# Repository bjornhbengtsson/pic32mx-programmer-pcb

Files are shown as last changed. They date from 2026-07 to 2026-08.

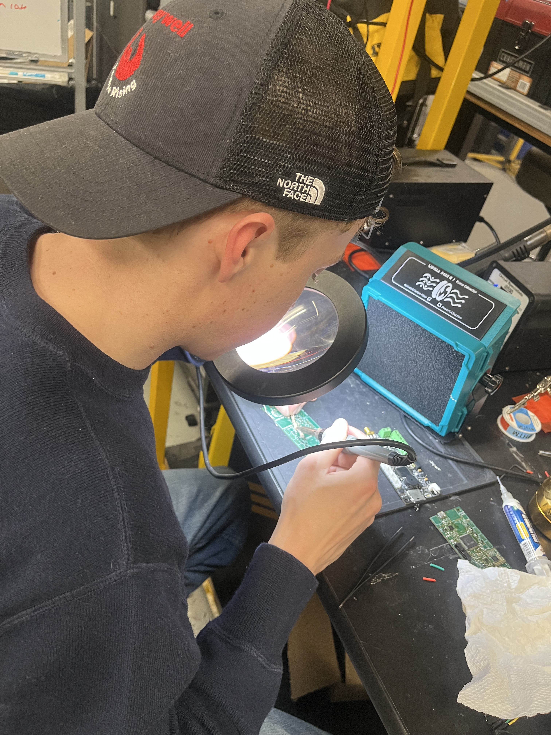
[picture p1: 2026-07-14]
images/Soldering.jpeg

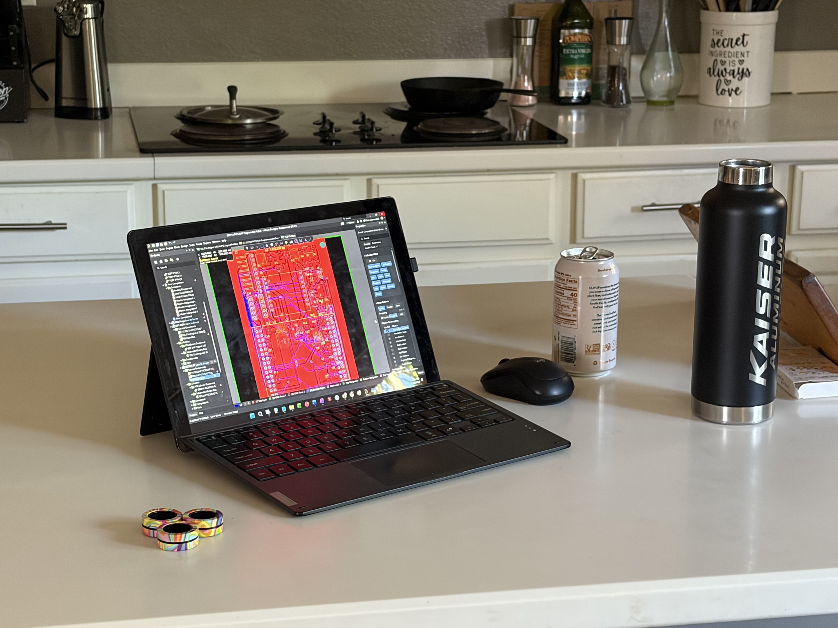
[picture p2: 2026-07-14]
images/Designing.jpeg

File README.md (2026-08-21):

# PIC32MX 64-Pin Programmer PCB

A reusable socketed programmer, USB bootloader, firmware flashing, and hardware-validation platform for 64-pin PIC32MX microcontrollers.

Programmer_Board_Product

[Programmer_PCB_REACH.pdf](https://github.com/user-attachments/files/31288978/Programmer_PCB_REACH.pdf)


## Overview

This project provides a development and test platform for PIC32MX 64-pin MCUs without requiring the microcontroller to be permanently soldered to a target PCB. A clamshell test socket allows an MCU to be inserted, powered, programmed, tested, removed, and reused.

The project was developed as an educational and research-oriented PCB platform using Altium Designer. The board is intended for firmware development, classroom instruction, early hardware validation, and low-volume embedded-system development.

## Target Device

- **Initial MCU:** Microchip PIC32MX534F064H-I/PT
- **Package:** 64-pin TQFP
- **Architecture:** 32-bit PIC32MX
- **Programming tools:** MPLAB PICkit 4 and MPLAB Snap

> Compatibility with other 64-pin PIC32MX devices must be verified against their package pinout, power requirements, and peripheral mappings. Contact me if you would like to commission a version adapted for a different MCU. bjorn.h.bengtsson@gmail.com

## Main Features

- 64-pin clamshell test socket
- ICSP programming and debugging
- USB bootloader support
- USB D+, D-, VBUS, and USB-ID connections
- MCLR/reset circuitry
- VCAP, oscillator, decoupling, and power-support circuitry
- CAN communication interface
- MikroBUS expansion socket
- Status LEDs and pushbuttons
- Peripheral breakout headers
- Power, ground, and signal test points

## ICSP Interface

The ICSP interface exposes:

- MCLR
- PGEC
- PGED
- VCC
- GND

## Repository Structure

```text
pic32mx-programmer-pcb/
├── README.md
├── CONTRIBUTING.md
├── LICENSE
├── docs/
│   ├── PIC32MX_Programmer_PCB_Poster.pdf
│   ├── PIC32MX_Project_Notes.pdf
│   └── README.md
├── firmware/
│   ├── bootloader/
│   └── README.md
├── hardware/
│   ├── altium/
│   ├── assembly/
│   ├── bom/
│   ├── gerbers/
│   ├── schematic/
│   ├── step/
│   └── README.md
└── images/
```

## Development Process

1. Learn Altium Designer
2. Create the schematic
3. Select and verify components
4. Complete the PCB layout
5. Apply manufacturing design rules
6. Generate fabrication and assembly files
7. Assemble the PCB
8. Perform electrical bring-up
9. Flash and validate firmware
10. Test USB bootloading and peripheral functions

## Design Challenges

- Mapping the MCU's 64 pins to the clamshell socket
- Routing the USB differential pair
- Maintaining mechanical clearance around the socket and headers
- Applying signal-integrity-aware routing
- Reducing Altium DRC violations
- Meeting PCB fabrication constraints
- Planning repeatable firmware and hardware validation

## Validation Status

### Completed

- Manufactured and assembled the PCB
- Inspected the power rails for shorts
- Verified the regulated supply voltages
- Successfully powered the assembled board

### Remaining

- Confirm MCLR behavior
- Detect the MCU with MPLAB
- Program a basic LED test
- Validate oscillator operation
- Validate USB enumeration
- Flash firmware through the USB bootloader
- Test CAN communication
- Test MikroBUS and breakout connections

## Manufacturing

The PCB was manufactured by JLCPCB and hand assembled.

The design is also intended for SMT assembly using the ASU Polytechnic manufacturing line. Gerber and drill outputs, a BOM, assembly drawings, a schematic PDF, and a STEP model are included. Placement files and test documentation will be added as the project is finalized.

## Project Status

Current stage: PCB manufactured, assembled, and successfully powered.

Basic power validation has been completed. The next step is to establish ICSP communication with the PIC32MX534F064H and program an initial test application using MPLAB X or MPLAB IPE.

## Author

**Bjorn Bengtsson**  
Electrical Engineering Student  
Arizona State University

- GitHub: [bjornhbengtsson](https://github.com/bjornhbengtsson)
- LinkedIn: [Bjorn Bengtsson](https://www.linkedin.com/in/bjorn-bengtsson-love/)

## Acknowledgments

Special thanks to John T. Lewis, Billal Abulfotuh, and Brad Bengtsson for their support and guidance.

## Custom Hardware Inquiries

Contact me if you would like to commission a version of this programmer adapted for a different MCU, package, pinout, programming interface, or set of peripherals.
- Contact: bjorn.h.bengtsson@gmail.com

## License

This repository is provided under the MIT License unless otherwise noted. Third-party component models, manufacturer documentation, and proprietary Altium libraries remain subject to their original licenses.

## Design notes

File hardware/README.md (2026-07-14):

# Hardware Files

This directory contains the editable PCB design sources and generated manufacturing outputs.

## Directory Structure

- `altium/` — Editable Altium project, schematic, PCB, and library files
- `assembly/` — Assembly drawings
- `bom/` — Bill of materials
- `gerbers/` — Gerber and NC drill fabrication files
- `schematic/` — Exported schematic PDF
- `step/` — Exported board-level STEP model

Generated manufacturing files should be regenerated from the approved Altium design rather than edited manually.

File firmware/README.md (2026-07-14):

# Firmware

Firmware for the PIC32MX534F064H programmer and validation board.

## Directories

- `bootloader/` — MPLAB X / XC32 USB bootloader project

MPLAB build outputs, private IDE settings, object files, and generated binaries are excluded through the repository `.gitignore`.

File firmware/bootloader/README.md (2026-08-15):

# PIC32MX534F064H USB HID Bootloader

This folder is the board-specific integration package for a **PIC32MX534F064H-I/PT** USB Device HID bootloader using:

- MPLAB X IDE
- MPLAB XC32
- MPLAB Code Configurator / Harmony 3
- PICkit 4 (`PG164140`) or MPLAB Snap (`PG164100`) for the one-time ICSP load
- Microchip Unified Host for later USB firmware updates

## Important status

The source in this package is the **board-specific code and reproducible integration recipe** around Microchip's generated Harmony 3 USB HID bootloader. Harmony-generated USB, NVM, interrupt, startup, and linker files must be generated for the exact target device in MPLAB X/MCC.

Completed checks in this package:

- Host compilation and unit testing of the bootloader trigger override
- Intel HEX parser tests
- Static memory-contract checks
- Review against Microchip's PIC32MX USB HID bootloader reference and PIC32MX534F064H memory/pin data

Still required before calling the firmware production-ready:

1. Generate the two MPLAB X projects for `PIC32MX534F064H`.
2. Build both with XC32.
3. Run `scripts/verify_project.py`.
4. Run `scripts/hex_layout.py` on both production HEX files.
5. Program and test a real MCU in the clamshell fixture.
6. Confirm USB enumeration and an application update through Unified Host.

This is a remote software-only review and thus cannot prove oscillator startup, USB signal integrity, socket contact, power integrity, or ICSP wiring on the physical PCB.

## Assumptions that must match the PCB

| Item | Assumed value |
|---|---|
| MCU | PIC32MX534F064H-I/PT, 64-TQFP |
| Primary oscillator | 8 MHz crystal on OSC1/OSC2 |
| CPU clock | 80 MHz |
| USB clock | 48 MHz from USB PLL |
| ICSP channel | PGEC1/PGED1 |
| Target voltage | 3.3 V |
| Initial programmer | PICkit 4 or MPLAB Snap |
| USB mode | Full-speed USB Device HID |
| USB VID/PID | `0x04D8 / 0x003C` |
| Bootloader PFM reservation | 32 KiB |
| Application download/reset page | `0x9D008000` |
| Application EBASE/code start | `0x9D009000` |
| SRAM | 16 KiB; first 16 bytes reserved for boot request |

Optional status LED and force-boot switch support are disabled by default. Enable these features in `source_overrides\/bootloader_board.h` after assigning their MCC-generated pin aliases.

## Folder layout

```text
README.md
BUILD_WITH_MPLAB_HARMONY.md
HARDWARE_SETUP.md
PROGRAM_WITH_PICKIT4_OR_SNAP.md
USB_UPDATE_AND_VALIDATION.md
VALIDATION_STATUS.md
REFERENCES.md
memory_contract.json
source_overrides/
  bootloader_app.c
  bootloader_board.h
  config_bits_8mhz.c
test_app_snippets/
  bootloader_request.c
  bootloader_request.h
  test_app_app.c
  test_app_board.h
scripts/
  hex_layout.py
  verify_project.py
  program_bootloader.ps1
  install_into_repo.ps1
  run_host_checks.py
tests/
  mocks/app.h
  mocks/definitions.h
  test_bootloader_app_host.c
  test_hex_layout.py
generated_projects/
  README.md
```

## Recommended workflow steps

### 1. Install the development tools

Install MPLAB X IDE, MPLAB XC32, and MCC/Harmony 3. A known Microchip reference combination for this example family is:

- MPLAB X IDE 6.25
- MPLAB XC32 4.60
- MCC 5.5.2

A newer compatible toolchain can be used, but record the exact versions in the commit.

### 2. Obtain the Microchip reference

Clone the official USB bootloader examples:

```powershell
git clone https://github.com/Microchip-MPLAB-Harmony/bootloader_apps_usb.git
```

Use this example as the closest reference:

```text
apps/usb_device_hid_bootloader/
  bootloader/firmware/pic32mx_125_sk.X
  test_app/firmware/pic32mx_125_sk.X
```

Do **not** program that project unchanged. It targets a larger PIC32MX device and has the wrong Flash and RAM sizes for this MCU.

### 3. Generate the target projects

Follow `BUILD_WITH_MPLAB_HARMONY.md`. Create:

```text
generated_projects/
  bootloader_pic32mx534.X/
  test_app_pic32mx534.X/
```

### 4. Replace/add the board-specific sources

For the bootloader project:

- Replace generated `src/app.c` with `source_overrides/bootloader_app.c`.
- Copy `source_overrides/bootloader_board.h` beside `app.c`.
- Add `source_overrides/config_bits_8mhz.c` to Source Files.
- Edit `bootloader_board.h` only after confirming the actual LED/switch pins.

For the test application:

- Replace its generated `src/app.c` with `test_app_snippets/test_app_app.c`.
- Copy `test_app_snippets/test_app_board.h` beside it.
- Add `bootloader_request.c/.h` when the application needs to request bootloader mode.

Do not add configuration-bit pragmas to the USB-loaded application.

### 5. Build and verify

From this folder:

```powershell
python scripts\verify_project.py `
  --bootloader generated_projects\bootloader_pic32mx534.X `
  --application generated_projects\test_app_pic32mx534.X
```

After MPLAB X creates both production HEX files:

```powershell
python scripts\hex_layout.py `
  --mode bootloader `
  generated_projects\bootloader_pic32mx534.X\dist\default\production\bootloader_pic32mx534.X.production.hex

python scripts\hex_layout.py `
  --mode application `
  generated_projects\test_app_pic32mx534.X\dist\default\production\test_app_pic32mx534.X.production.hex
```

Expected result: both commands end with `PASS`.

### 6. Program the one-time bootloader over ICSP

Read `HARDWARE_SETUP.md`, then:

```powershell
powershell -ExecutionPolicy Bypass -File scripts\program_bootloader.ps1 `
  -Tool PICkit4 `
  -Hex generated_projects\bootloader_pic32mx534.X\dist\default\production\bootloader_pic32mx534.X.production.hex
```

For Snap, replace `PICkit4` with `Snap`.

### 7. Load the test application over USB

Follow `USB_UPDATE_AND_VALIDATION.md`.

## Memory map

```text
PIC32MX534F064H Program Flash: 64 KiB

0x9D000000 +------------------------------+
             | USB HID bootloader         |
             | 32 KiB reserved            |
0x9D008000 +------------------------------+
             | Application reset page     |
             | reset entry at 0xBD008000  |
0x9D009000 +------------------------------+
             | Application EBASE, vectors |
             | and normal code            |
0x9D010000 +------------------------------+

SRAM: 16 KiB

0xA0000000 +------------------------------+
             | 16-byte boot request       |
0xA0000010 +------------------------------+
             | Application/bootloader RAM |
0xA0004000 +------------------------------+
```

`0x9D...` and `0xBD...` are cached/uncached virtual aliases of the same physical Program Flash. The first application erase page begins at physical address `0x1D008000`.

## Safety rules

- Never connect an unpowered target to a powered programmer unless the tool documentation explicitly permits that setup.
- Prefer external regulated 3.3 V power and use the programmer's TVDD pin as voltage sense.
- Do not enable programmer target power while USB or another 3.3 V source is already powering the board.
- Pin 1 orientation on the ICSP cable and the clamshell socket must be verified before insertion.
- Do not place capacitors, LEDs, pull-ups, or other loads on PGEC1/PGED1.
- Keep code protection and write protection off until development and recovery testing are complete.

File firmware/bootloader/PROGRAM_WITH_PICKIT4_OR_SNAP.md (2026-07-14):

# One-time ICSP programming with PICkit 4 or MPLAB Snap

A blank PIC32 cannot update itself over USB. The USB HID bootloader must first be loaded through ICSP.

## Method 1: MPLAB X IDE

1. Open `bootloader_pic32mx534.X`.
2. Open **Project Properties**.
3. Confirm:
   - Device: `PIC32MX534F064H`
   - Compiler: XC32
   - Hardware tool: PICkit 4 or Snap
4. Confirm the board is externally powered at 3.3 V.
5. Confirm tool power is disabled.
6. Select **Clean and Build Project**.
7. Select **Make and Program Device**.
8. Review the output window for:
   - device detected
   - erase complete
   - programming complete
   - verification complete

Do not use the test application's normal linker project for this step.

## Method 2: MPLAB IPE GUI

1. Open MPLAB IPE.
2. Device: `PIC32MX534F064H`.
3. Tool: PICkit 4 or Snap.
4. Click **Connect**.
5. Confirm target voltage.
6. Browse to:

```text
bootloader_pic32mx534.X/
  dist/default/production/
    bootloader_pic32mx534.X.production.hex
```

7. Click **Erase**.
8. Click **Blank Check**.
9. Click **Program**.
10. Confirm **Programming/Verify complete**.
11. Read back the device where permitted and save the IPE log.

## Method 3: IPECMD PowerShell script

The included script locates `ipecmd.exe` under a normal MPLAB X installation.

PICkit 4:

```powershell
powershell -ExecutionPolicy Bypass -File scripts\program_bootloader.ps1 `
  -Tool PICkit4 `
  -Hex generated_projects\bootloader_pic32mx534.X\dist\default\production\bootloader_pic32mx534.X.production.hex
```

Snap:

```powershell
powershell -ExecutionPolicy Bypass -File scripts\program_bootloader.ps1 `
  -Tool Snap `
  -Hex generated_projects\bootloader_pic32mx534.X\dist\default\production\bootloader_pic32mx534.X.production.hex
```

The script uses:

```text
-TPPK4   for PICkit 4
-TPSNAP  for MPLAB Snap
-P32MX534F064H
-E       erase
-M       program
-Y       verify
-OL      release from reset after operation
```

Run the installed `ipecmd.exe -?` and inspect MPLAB X's local **Readme for IPECMD** if a newer IPE version changes an option.

## Programmer power

The script intentionally does not request target power. The PCB should be powered from a regulated 3.3 V source, and TVDD should be used for voltage sensing.

Do not add a target-power option while USB or another power source is connected.

## First boot after ICSP programming

1. Disconnect the programmer or leave it connected without holding reset.
2. Keep the board powered.
3. Connect the board's USB device connector to the PC.
4. With no valid application in `0x9D008000`, `run_Application()` returns and the bootloader remains active.
5. Windows should enumerate a HID device with VID/PID `04D8:003C`.

HID does not require a custom Windows kernel driver.

## Recovering a board

PICkit 4 or Snap remains the recovery path even after the USB bootloader is installed.

Use ICSP recovery when:

- the bootloader region was corrupted
- configuration bits were changed incorrectly
- USB clocking no longer works
- an application repeatedly resets before bootloader entry
- the USB descriptor no longer matches Unified Host
- the application linker overwrote the bootloader

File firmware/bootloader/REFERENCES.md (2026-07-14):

# Primary references

Accessed during the July 2026 design review.

## Microchip device and programming documents

- PIC32MX534F064H product page  
  https://www.microchip.com/en-us/product/pic32mx534f064h
- PIC32MX5XX/6XX/7XX Family Data Sheet, DS60001156K  
  https://ww1.microchip.com/downloads/en/DeviceDoc/PIC32MX5XX-6XX-7XX-Family-Data-Sheet-DS60001156K.pdf
- PIC32 Flash Programming Specification, DS60001145  
  https://ww1.microchip.com/downloads/aemDocuments/documents/MCU32/ProductDocuments/ProgrammingSpecifications/PIC32-Flash-Programming-Specification-DS60001145.pdf
- PIC32MX534/564/664/764 Family Silicon Errata, DS80000511L  
  https://ww1.microchip.com/downloads/aemDocuments/documents/MCU32/ProductDocuments/Errata/PIC32MX534564664764_Family_DS80000511L.pdf

## Harmony USB HID bootloader

- Official repository  
  https://github.com/Microchip-MPLAB-Harmony/bootloader_apps_usb
- USB Device HID bootloader example documentation  
  https://onlinedocs.microchip.com/oxy/GUID-90F6CA10-E41C-4317-A3AA-CB049A76D4F0-en-US-5/GUID-BDA62187-954D-482E-9B03-29797BA6ABA8.html
- Closest PIC32MX reference project  
  https://github.com/Microchip-MPLAB-Harmony/bootloader_apps_usb/tree/master/apps/usb_device_hid_bootloader/bootloader/firmware/pic32mx_125_sk.X
- Reference test application  
  https://github.com/Microchip-MPLAB-Harmony/bootloader_apps_usb/tree/master/apps/usb_device_hid_bootloader/test_app/firmware/pic32mx_125_sk.X

## Programmer/debugger documents

- MPLAB PICkit 4 In-Circuit Debugger User's Guide  
  https://ww1.microchip.com/downloads/aemDocuments/documents/DEV/ProductDocuments/UserGuides/MPLAB-PICkit-4-In-Circuit-Debugger-Users-Guide-DS50002751.pdf
- MPLAB Snap In-Circuit Debugger User's Guide  
  https://ww1.microchip.com/downloads/aemDocuments/documents/DEV/ProductDocuments/UserGuides/MPLAB-Snap-In-Circuit-Debugger-User-Guide-50002787.pdf

## Project-specific supplied notes

The supplied nine-page project notes were also reviewed for the intended 8 MHz crystal, clamshell fixture, ICSP header, VCAP, USB pins, PICkit/Snap workflow, and board assumptions. Exact LED and switch GPIO net labels were not legible enough to use safely.

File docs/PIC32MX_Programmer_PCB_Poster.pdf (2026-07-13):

# A Custom 32-bit, 64-Pin PIC32MX MCU Compatible PCB for USB Bootloading, Firmware Flashing & Hardware Validation

# Programmer PCB

Arizona State University

# Bjorn Bengtsson

# METHODOLOGY / PROCESS

# BACKGROUND & GOALS

# RESULTS / RESEARCH UTILITY

# PROCESS

## 1. Learn Altium Designer

## 2. Schematic Design

## 3. Component Selection

## 4. PCB Layout

## 5. PCB Ordering

## 6. PCB Assembly

## 7. PCB Test / Validation

# GOAL

## MCUs (microcontroller units) are COTS (commercial off the shelf) ICs (integrated circuits) functioning on a PCB as a single

chip computer with a processor,

## memory, I/O peripherals for external PCB hardware -

sensors, motors, displays, LEDs.. MCU’s come with blank memory.

## To use the MCU we must first write bootloader firmware to the internal flash memory using a

programmer.

### Traditional MCU firmware testing depends on an assembled target board, where the MCU is soldered in place and programmed through an additional external header. This limits flexibility during bootloader development; hardware mistakes

may require rework, replacement,

### or a new board revision - ramping

up cost and time to manufacture.

# MCU FIRMWARE

Create a novel PCB bootloader,

## firmware flashing & hardware testing platform compatible with any PIC32MX 64-pin MCU, ready

for use in research and industry.

A reusable socketed bootloader board with modularity for any PIC32MX 64-pin MCU. The clamshell socket allows the MCU to be powered, programmed, and tested without soldering directly to a PCB. Supporting ICSP firmware flashing, USB bootloading, reset/MCLR validation, peripheral breakout, CAN communication and hardware verification. MPLAB Snap In-Circuit

Debugger PG164100

64-Bit MCU: PIC32MX534F064H-I/PT

MPLAB PICKIT 4
PG164140

Bootload Firmware Example

# PROBLEM

64-Pin Clamshell Socket

LEDs

USB Connector | MIKROBUS Socket

1x8 Programmer Socket

SCHEMATIC DESIGN | PCB LAYOUT

64-pin MCU -> socket pin mapping

USB differential pair D+/D− routing

3D Socket and header clearance

Signal integrity (SIG, GND, GND, SIG)

DRC errors 130 -> 18

JLCPCB manufacturing rules

Firmware test validation

CHALLENGES | PCB ASSEMBLY, TEST, & VALIDATION

Solder paste printing

Component placement

Reflow soldering

To be manufactured in ASU POLY’s SMT (surface mount technology) line in support of advanced semiconductor packaging research.

To be used Fall 26’ in classroom for educational support of students and teachers in PCB design

Socketed programmer boards help industry teams reduce rework by testing firmware and hardware before committing MCUs to final assemblies.
The target users include embedded-system developers, university labs, PCB design courses, research teams, and low-volume electronics manufacturers. The board provides a practical tool for firmware flashing, bootloader validation, and hardware testing during early product development.

# ASU POLYTECHNIC SMT

# ASU EEE 314

# RESEARCH, INDUSTRY, & MARKET

# FINAL PRODUCT DESIGN

USB bootloader support: D+, D−, VBUS, USB-ID
Required support circuits: VCAP, oscillator, reset, decoupling Expansion/testing: CAN, LEDs, buttons, headers, MikroBUS

PIC32MX534F064H 64-pin MCU requirements
ICSP programming: MCLR, PGEC, PGED, VCC, GND

# DESIGN INPUTS

John T Lewis, Billal Abulfotuh, & Brad Bengtsson

Special thanks to:

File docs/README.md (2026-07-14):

# Project Documentation

This directory contains supporting project documentation.

- `PIC32MX_Programmer_PCB_Poster.pdf` — Project presentation poster
- `PIC32MX_Project_Notes.pdf` — Design and development notes

Hardware manufacturing documents are organized under the `hardware/` directory.

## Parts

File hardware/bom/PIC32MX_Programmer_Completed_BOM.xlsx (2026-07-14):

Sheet: Completed BOM
Index | Qty Per Board | Ref Des | DigiKey Part Number | Manufacturer Part Number | Manufacturer | Description | Change Status | Notes
1 | 1 | U1 | PIC32MX534F064H-I/PT-ND | PIC32MX534F064H-I/PT | Microchip Technology | IC MCU 32-bit, 64KB Flash, 64-TQFP | Legacy / unchanged | Target MCU; verify whether ordered separately from the clamshell socket
2 | 2 | T1, T2 | CKN12220-1-ND | PTS526SM15SMTR2LFS | C&K | Tactile switch, SPST-NO, SMD | Legacy / unchanged
3 | 4 | R1, R2, R8, R9 | RMCF1206JT4K70CT-ND | RMCF1206JT4K70 | Stackpole Electronics | 4.7 kΩ, 5%, 1/4 W, 1206 resistor | Legacy / unchanged
4 | 8 | C5, C8, C9, C10, C11, C14, C15, C18 | 709-AMDD251W104K1GF002ECT-ND | AMDD251W104K1GF002E | American Technical Ceramics / KYOCERA AVX | 100 nF, 10%, X7R, 1206 ceramic capacitor | Modified | Added CAN-transceiver decoupling capacitor C18
5 | 1 | C16 | 1276-1291-1-ND | CL31B225KBHNNNE | Samsung Electro-Mechanics | 2.2 µF, 50 V, X7R, 1206 ceramic capacitor | Legacy / unchanged
6 | 2 | R12, R13 | 311-27ERCT-ND | RC1206JR-0727RL | YAGEO | 27 Ω, 5%, 1/4 W, 1206 resistor | Legacy / unchanged | USB series resistors
7 | 1 | R11 | RMCF1206FT220RCT-ND | RMCF1206FT220R | Stackpole Electronics | 220 Ω, 1%, 1/4 W, 1206 resistor | Legacy / unchanged
8 | 1 | J1 | 609-4701-1-ND | 10033526-N3212MLF | Amphenol Communications Solutions | Mini-USB Type-B receptacle, 5-position, right-angle SMD | Legacy / unchanged
9 | 1 | FP1 | 240-2410-1-ND | HI1206P121R-10 | Laird-Signal Integrity Products | Ferrite bead, 120 Ω, 1206 | Legacy / unchanged
10 | 1 | X2 | SER4103CT-ND | FC-135 32.7680KA-A5 | Epson | 32.768 kHz crystal, 12.5 pF, SMD | Legacy / unchanged
11 | 1 | X3 | 110-407F39E008M0000CT-ND | 407F39E008M0000 | CTS Frequency Controls | 8.000 MHz crystal, 20 pF, 60 Ω, 4-SMD | Replaced | Replaces legacy X1 ATS08ASM-1E; current schematic designator is X3
12 | 4 | C1, C3, C4, C6 | 1276-1203-1-ND | CL31C220JBCNNNC | Samsung Electro-Mechanics | 22 pF, 50 V, C0G/NP0, 1206 ceramic capacitor | Legacy / unchanged | Crystal load capacitors
13 | 1 | R4 | 311-100KRCT-ND | RC1206FR-07100KL | YAGEO | 100 kΩ, 1%, 1/4 W, 1206 resistor | Legacy / unchanged
14 | 1 | J5 | 1471-MIKROE-4247-ND | MIKROE-4247 | MikroElektronika | mikroBUS socket, 16-position, through-hole | Legacy / unchanged
15 | 1 | R7 | RNCP1206FTD1K00CT-ND | RNCP1206FTD1K00 | Stackpole Electronics | 1 kΩ, 1%, 1/2 W, 1206 resistor | Legacy / unchanged
16 | 1 | R6 | RMCF1206FT10K0CT-ND | RMCF1206FT10K0 | Stackpole Electronics | 10 kΩ, 1%, 1/4 W, 1206 resistor | Legacy / unchanged
17 | 1 | T3 | CKN12330-1-ND | GSPTS004602 | C&K | Tactile switch, SPST-NO, SMD | Legacy / unchanged
18 | 2 | LED1, LED2 | 160-1168-1-ND | LTST-C150EKT | Lite-On | Red clear LED, 1206 SMD | Legacy / unchanged
19 | 1 | LED3 | 160-1456-1-ND | LTST-C230KGKT | Lite-On | Green clear right-angle/bottom-entry SMD LED | Legacy / unchanged
20 | 1 | R10 | 311-470ERCT-ND | RC1206JR-07470RL | YAGEO | 470 Ω, 5%, 1/4 W, 1206 resistor | Legacy / unchanged
21 | 3 | C2, C7, C12 | 1276-1804-1-ND | CL31B106KAHNNNE | Samsung Electro-Mechanics | 10 µF, 25 V, X7R, 1206 ceramic capacitor | Legacy / unchanged
22 | 1 | U2 | 497-4243-1-ND | LD29080DT33R | STMicroelectronics | 3.3 V, 800 mA linear regulator, DPAK | Legacy / unchanged
23 | 1 | J2 | 732-5341-ND | 61300811021 | Würth Elektronik | 8-position, 2.54 mm, single-row right-angle THT header | Modified connector | Current Altium BOM identifies J2 as the programmer port
24 | 2 | J3, J4 | 732-5318-ND | 61300511121 | Würth Elektronik | 5-position, 2.54 mm, single-row vertical THT header | Connector / socket interface | Assumed from the legacy BOM; verify against the exact clamshell adapter hardware
25 | 1 | U3 | MCP2561-E/SN-ND | MCP2561-E/SN | Microchip Technology | High-speed CAN transceiver, 8-SOIC | Added - CAN bus
26 | 1 | C17 | 311-4450-1-ND | CC1206JRX7R9BB472 | YAGEO | 4.7 nF, 50 V, X7R, 1206 ceramic capacitor | Added - CAN bus | Split-termination capacitor
27 | 1 | R15 | RMCF1206JT300RCT-ND | RMCF1206JT300R | Stackpole Electronics | 300 Ω, 5%, 1/4 W, 1206 resistor | Added - CAN bus | CAN transceiver control/bias resistor per schematic
28 | 2 | R16, R17 | 541-CRCW120660R0KNEAIFCT-ND | CRCW120660R0KNEAIF | Vishay Dale | 60 Ω, 10%, 1/4 W, 1206 resistor | Added - CAN bus | Two 60 Ω resistors form the split 120 Ω CAN termination
29 | 1 | J6 | 609-3500-ND | 68000-102HLF | Amphenol Communications Solutions | 2-position, 2.54 mm, single-row THT header | Added - CAN bus | CANH/CANL connector

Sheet: Change Summary
Category | Designators | Action / Result
8 MHz crystal | X3 | Use CTS 407F39E008M0000 instead of legacy ATS08ASM-1E. Designator changed from X1 to X3.
CAN transceiver | U3 | Added MCP2561-E/SN.
CAN termination | R16, R17, C17 | Added split termination: 60 Ω + 60 Ω with 4.7 nF midpoint capacitor to ground.
CAN support | R15, C18 | Added 300 Ω resistor and 100 nF local bypass capacitor.
CAN connector | J6 | Added 2-position header for CANH/CANL.
Programmer header | J2 | Updated to 8-position right-angle header 61300811021.
Clamshell interface | J3, J4 | Retained 5-position headers from legacy BOM as an assumption; verify exact socket adapter mating hardware.
MCU/socket handling | U1 | The schematic combines the target MCU and clamshell concept. Confirm whether the MCU and socket must be purchased as separate line items.

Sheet: Read Me
Completed BOM - Verification Notes
This workbook separates the Altium-exported grouped components into actual value-specific purchasing rows.
Green rows are newly added CAN-bus parts. Yellow rows are modified or replaced items.
Two items still need physical-hardware confirmation before ordering:
1. J3/J4 exact 5-pin headers that mate with the clamshell socket adapter.
2. Whether U1 should represent only the clamshell socket, with the PIC32 MCU purchased as a separate non-soldered target device.
The selected R16/R17 parts are exact 60 Ω, 10%, 1206 resistors, matching the schematic value.
The selected C17 is a 4.7 nF, 50 V, X7R, 1206 capacitor.

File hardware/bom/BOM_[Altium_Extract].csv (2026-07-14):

Line # | Name | Description | Designator | Revision ID | Revision State | Revision Status | Quantity | Manufacturer 1 | Manufacturer Part Number 1 | Manufacturer Lifecycle 1 | Supplier 1 | Supplier Part Number 1 | Supplier Unit Price 1 | Supplier Subtotal 1
 | 22pf, 10uf, 100nf, 2.2uf | Automotive Ceramic Capacitor, 1206, 100nF, 10%, X7R, 15%, 200V | C1, C2, C3, C4, C5, C6, C7, C8, C9, C10, C11, C12, C14, C15, C16, C18 | CMP-04427-012685-1 | New From Design | Up to date | 16 | KYOCERA AVX | 12062C104K4T2A | Volume Production | Mouser | 581-12062C104K4T2A | 0.348 | 5.568
 | 4700pF | Automotive Ceramic Capacitor, 1206, 100nF, 10%, X7R, 15%, 200V | C17 |  | Not managed |  | 1
 | HI1206P121R-10 | Description | FP1 |  | Not managed |  | 1
 | Programmer Port | THT Angled Pin Header WR-PHD, Pitch 2.54 mm, Single Row, 8 pins | J2 | CMP-1502-01075-4 | Released | Up to date | 1 | Wurth Elektronik | 61300811021 | Volume Production | DigiKey | 732-5341-ND | 0.75 | 0.75
 | 1-5 |  | J3 |  | Not managed |  | 1
 | 6-10 |  | J4 |  | Not managed |  | 1
 | MIKROE-4247 | Sockets & Adapters SOCKET mikroBUS 16 TH | J5 |  | Not managed |  | 1
 | 68000-102HLF | Male Header, Pitch 2.54 mm, 1 x 2 Position, Height 8.38 mm, Tail Length 2.41 mm, RoHS, Bulk | J6 | CMP-2000-05666-1 | Released | Up to date | 1 | Amphenol Communications Solutions | 68000-102HLF | Volume Production | DigiKey | 609-3500-ND | 0.23 | 0.23
 | LTST-C150EKT | Description | LED1, LED2 |  | Not managed |  | 2
 | LTST-C230KGKT | LED GREEN CLEAR CHIP SMD | LED3 |  | Not managed |  | 1
 | 4K7, 100k, 10k, 1k, 470, 220, 27 | 4.7kΩ ±5% 0.25W 1206 Thick Film Chip Resistor AEC-Q200 compliant | R1, R2, R4, R6, R7, R8, R9, R10, R11, R12, R13 | CMP-26527-005426-1 | New From Design | Up to date | 11 | Stackpole Electronics | RMCF1206JT4K70 | Volume Production | Mouser | 708-RMCF1206JT4K70 | 0.017 | 0.187
 | 300 | 300Ω ±5% 0.25W 1206 Thick Film Chip Resistor AEC-Q200 compliant | R15 | CMP-26527-001830-1 | New From Design | Up to date | 1 | Stackpole Electronics | RMCF1206JT300R | Volume Production | DigiKey | RMCF1206JT300RCT-ND | 0.1 | 0.1
 | 60 | 60 Ohms Â±10% 0.25W, 1/4W Chip Resistor 1206 (3216 Metric) Automotive AEC-Q200, Pulse Withstanding Thick Film | R16, R17 |  | Not managed |  | 2
 | PTS526 SM15 SMTR2 LFS | Description | T1, T2 |  | Not managed |  | 2
 | GSPTS004602 | Tactile Switch SPST-NO Top Actuated Surface Mount 0.05A,12VDC ,-40C ~ 90C,"PTS636SK25FSMTR LFS" | T3 |  | Not managed |  | 1
 | PIC32MX534F064H-I/PT - Clamshell | Description | U1 |  | Not managed |  | 1
 | LD29080DT33R | 800 mA fixed and adjustable output very low drop voltage regulator | U2 |  | Not managed |  | 1
 | MCP2561-E/SN | Description | U3 |  | Not managed |  | 1
 | 32.7680KHz | Description | X2 |  | Not managed |  | 1
 | 407F39E008M0000 | 8 MHz Â±30ppm Crystal 20pF 60 Ohms 4-SMD, No Lead | X3 | CMP-003-00030-1 | Draft | Up to date | 1
 | USB Conn | Right Angle Surface Mount Mount Female Type B USB Connector | Amphenol FCI (Amphenol CS) 10033526-N3212MLF | J1 |  | Not managed |  | 1

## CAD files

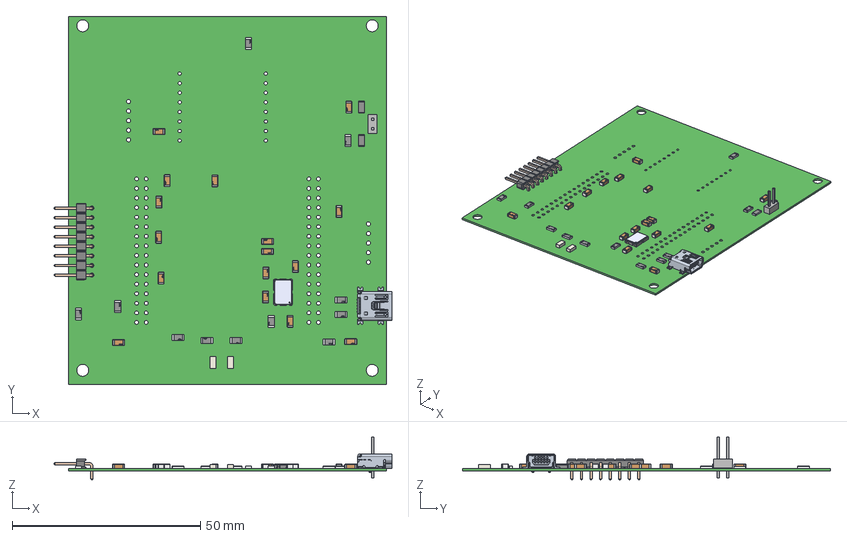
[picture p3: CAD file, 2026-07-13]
hardware/altium/PCB-BL-2.step
89.7 x 97.8 x 11.3 mm
terminals x 27
top x 11
logo x 27
Extruded x 5
6130xx11021_PIN x 8

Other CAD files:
hardware/step/STEP_[No Variations] for PCB-BL-2.PcbDoc.step

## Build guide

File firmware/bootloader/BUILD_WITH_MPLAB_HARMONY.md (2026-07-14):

# Build the bootloader and test application in MPLAB X/Harmony 3

## Why the project must be generated for the exact MCU

The Microchip `pic32mx_125_sk.X` example targets `PIC32MX570F512L`, which has much more Program Flash and SRAM than the PIC32MX534F064H. Copying its generated linker files unchanged can place data beyond the target's 16 KiB SRAM and can let the application exceed the target's 64 KiB Program Flash.

The correct process is to use the Microchip example as the functional reference, then have MCC generate startup, peripheral, USB, NVM, interrupt, and linker content for `PIC32MX534F064H`.

## Project A: USB HID bootloader

### A1. Create the project

1. Open MPLAB X IDE.
2. Select **File → New Project**.
3. Select **Microchip Embedded → Standalone Project**.
4. Device: `PIC32MX534F064H`.
5. Hardware Tool: PICkit 4, Snap, or Simulator for project creation.
6. Compiler: installed MPLAB XC32.
7. Project name: `bootloader_pic32mx534`.
8. Put it under `generated_projects`.

### A2. Open MCC

1. Open **Tools → Embedded → MPLAB Code Configurator**.
2. Install the Harmony 3 content requested by MCC.
3. Open the Microchip `pic32mx_125_sk.X` bootloader in a second MPLAB X window as a settings reference.

### A3. Add the required Harmony components

Add or confirm these components in the Project Graph:

- Core / Harmony Core
- NVM peripheral library
- USBFS driver
- USB Device Layer
- USB Device HID Function Driver, instance 0
- USB Device HID Bootloader
- GPIO and EVIC support generated by Core

The USB stack must be in **device** mode. Host support is not required.

Expected logical connections:

```text
USB Device HID Bootloader
        |
USB Device HID Function 0
        |
USB Device Layer
        |
USBFS Driver

USB HID Bootloader
        |
NVM PLIB
```

Use the auto-connect suggestions where MCC provides them.

### A4. Configure clocks for the 8 MHz crystal

Use MCC's clock configuration and verify the generated configuration bits.

Required clock relationship:

```text
Primary crystal = 8 MHz
System PLL input divider = 2
System PLL multiplier = 20
System PLL output divider = 1
SYSCLK = 80 MHz

USB PLL input divider = 2
USB PLL input = 4 MHz
USB clock = 48 MHz
```

Expected essential settings:

```c
FNOSC    = PRIPLL
POSCMOD  = HS
FPLLIDIV = DIV_2
FPLLMUL  = MUL_20
FPLLODIV = DIV_1
UPLLEN   = ON
UPLLIDIV = DIV_2
FPBDIV   = DIV_1
```

Copy `source_overrides/config_bits_8mhz.c` into the bootloader project. Do not keep a second file that defines the same configuration bits.

If the physical oscillator is not an 8 MHz crystal, stop and recalculate the PLL configuration.

### A5. Configure the USB descriptors

Use:

```text
Vendor ID:  0x04D8
Product ID: 0x003C
Device class/function: HID custom device
EP0 size: 64 bytes
```

The Unified Host setting must use Product ID `3C`.

### A6. Configure bootloader memory

Use a Program Flash bootloader with a 32 KiB reservation.

Required generated constants:

```c
FLASH_START       0x9D000000
FLASH_LENGTH      0x00010000
BOOTLOADER_SIZE   32768
APP_START_ADDRESS 0x9D008000
APP_JUMP_ADDRESS  0x9D008000
BTL_TRIGGER_LEN   16
```

For this PIC32MX family, the expected NVM geometry is:

```text
Write row:  128 words = 512 bytes
Erase page: 1024 words = 4096 bytes
```

The generated `bootloader_common.h` commonly represents those in words:

```c
PAGE_SIZE       128
ERASE_BLOCK_SIZE 1024
```

Required bootloader linker memory regions:

```ld
kseg0_program_mem : ORIGIN = 0x9D000000, LENGTH = 0x8000
kseg1_data_mem    : ORIGIN = 0xA0000010, LENGTH = 0x3FF0
```

MCC may emit `32768` instead of `0x8000`, and `16384 - 16` instead of `0x3FF0`; those are equivalent.

The first 16 bytes of SRAM are reserved for the boot request pattern.

### A7. Configure ICSP channel and development protections

Required during development:

```c
ICESEL = ICS_PGx1
JTAGEN = OFF
FWDTEN = OFF
PWP    = OFF
BWP    = OFF
CP     = OFF
```

`ICESEL = ICS_PGx1` matches PGEC1/PGED1 on MCU pins 15/16.

### A8. Generate and add the source override

1. Click **Generate** in MCC.
2. Replace generated `src/app.c` with `source_overrides/bootloader_app.c`.
3. Copy `source_overrides/bootloader_board.h` beside it.
4. Add `source_overrides/config_bits_8mhz.c` to the project.
5. Keep the MCC-generated Harmony bootloader, USB, USBFS, NVM, startup, and linker source.

The override implements:

- `0x5048434D` RAM request pattern
- optional force-boot switch
- optional bootloader-active LED
- default no-switch/no-LED operation when board pin aliases are not yet known

The generated weak `bootloader_Trigger()` is overridden by this source.

### A9. Build

Select **Production** build, then **Clean and Build Project**.

Inspect:

```text
dist/default/production/bootloader_pic32mx534.X.production.hex
dist/default/production/bootloader_pic32mx534.X.production.map
```

The bootloader's PFM sections must stay below `0x9D008000`.

Run:

```powershell
python scripts\verify_project.py --bootloader generated_projects\bootloader_pic32mx534.X
python scripts\hex_layout.py --mode bootloader path\to\bootloader.production.hex
```

## Project B: USB-loaded test application

### B1. Create the project

Create another standalone project:

```text
Device: PIC32MX534F064H
Project: test_app_pic32mx534
```

### B2. Configure its clock and application peripherals

The application runs after the bootloader and still needs the same 80 MHz clock runtime assumptions. However, the USB-loaded application HEX must not carry device configuration words.

Do not add `config_bits_8mhz.c` to this project.

### B3. Configure the bootloader-aware application linker

The correct target linker contract is:

```ld
PROVIDE(_ebase_address = 0x9D009000);

_RESET_ADDR = 0xBD008000;

kseg0_program_mem :
    ORIGIN = 0x9D009000,
    LENGTH = 0x7000

kseg1_boot_mem :
    ORIGIN = 0xBD008000,
    LENGTH = 0x490

kseg1_data_mem :
    ORIGIN = 0xA0000010,
    LENGTH = 0x3FF0
```

Meaning:

- First 32 KiB of PFM belongs to the bootloader.
- The application's reset entry uses the first page after the bootloader.
- EBASE and interrupt vectors begin on the next 4 KiB boundary.
- About 28 KiB remains for normal application code.
- First 16 SRAM bytes stay reserved.

Use the MCC bootloader application-linker generation feature where available. Compare its result to the contract above rather than pasting a linker from another MCU.

### B4. Add the visible test

1. Replace generated `src/app.c` with `test_app_snippets/test_app_app.c`.
2. Copy `test_app_snippets/test_app_board.h` beside it.
3. Map `TEST_APP_LED_*` macros to an actual LED pin.
4. Add `bootloader_request.c/.h` when the application must request a reset into bootloader mode.

### B5. Build but do not program with PICkit/Snap

Build the production HEX:

```text
dist/default/production/test_app_pic32mx534.X.production.hex
```

Run:

```powershell
python scripts\verify_project.py --application generated_projects\test_app_pic32mx534.X
python scripts\hex_layout.py --mode application path\to\test_app.production.hex
```

The application HEX must not contain:

- Program Flash below physical `0x1D008000`
- Boot Flash/config words
- Code beyond physical `0x1D00FFFF`

Load this HEX through Unified Host.

## Build-time acceptance checklist

- [ ] Device string is `PIC32MX534F064H`.
- [ ] No stale `PIC32MX570F512L` text remains in generated target files.
- [ ] CPU frequency is 80 MHz.
- [ ] USB clock is 48 MHz.
- [ ] Bootloader `FLASH_LENGTH` is `0x10000`.
- [ ] Bootloader reservation is `0x8000`.
- [ ] Application jump address is `0x9D008000`.
- [ ] Application EBASE is `0x9D009000`.
- [ ] RAM length is 16 KiB minus the 16-byte trigger.
- [ ] VID/PID is `04D8/003C`.
- [ ] Application HEX excludes configuration words.
- [ ] Both HEX layout checks pass.

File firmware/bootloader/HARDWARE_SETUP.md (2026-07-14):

# Hardware setup: PCB, clamshell, PICkit 4, and MPLAB Snap

## 1. Insert the MCU correctly

The PIC32MX534F064H-I/PT is a 64-lead TQFP. Confirm:

- Socket body and contact pitch: 64-TQFP, 10 mm × 10 mm body, 0.50 mm pitch
- MCU pin 1 marker matches clamshell pin 1
- Clamshell adapter pin 1 matches PCB socket/header pin 1
- No bent leads or debris
- Lid is fully latched and applies even pressure

A 90-degree rotation can damage the MCU or board when power is applied.

## 2. Required MCU power connections

All supplies must be present:

- Every VDD pin to regulated 3.3 V
- Every VSS pin to ground
- AVDD to 3.3 V
- AVSS to ground
- VCAP to its required low-ESR capacitor to ground
- Decoupling capacitors close to each power pin pair

For this package, the important dedicated connections include:

| MCU pin | Signal |
|---:|---|
| 7 | MCLR |
| 15 | PGEC1 |
| 16 | PGED1 |
| 19 | AVDD |
| 20 | AVSS |
| 33 | USBID |
| 34 | VBUS |
| 35 | VUSB3V3 |
| 36 | USB D- |
| 37 | USB D+ |
| 39 | OSC1 |
| 40 | OSC2 |
| 56 | VCAP |
| 58 | C1RX/RF0 |
| 59 | C1TX/RF1 |

The CAN transceiver is unrelated to initial USB bootloader programming and can remain idle.

## 3. VCAP

VCAP is the internal regulator output. It is not another 3.3 V supply input.

Required:

```text
VCAP → low-ESR capacitor → GND
```

A typical value is 10 µF, subject to the exact device data sheet and capacitor ESR requirement.

Do not:

- connect VCAP directly to VDD
- power another circuit from VCAP
- omit the capacitor

## 4. MCLR

Recommended development connection:

```text
MCLR → 10 kΩ pull-up → 3.3 V
MCLR → programmer pin 1
```

Avoid a large capacitor directly on MCLR during programming. It can prevent the programmer from generating the required VPP/reset transition.

## 5. ICSP header mapping

### Standard six-signal mapping

| ICSP position | Signal | Connect to PIC32MX534F064H |
|---:|---|---|
| 1 | VPP / MCLR | MCU pin 7, MCLR |
| 2 | TVDD / target VDD sense | Board 3.3 V |
| 3 | VSS | Board ground |
| 4 | PGD / ICSPDAT | MCU pin 16, PGED1 |
| 5 | PGC / ICSPCLK | MCU pin 15, PGEC1 |
| 6 | AUX | Leave unconnected for normal ICSP |

The project configuration must use:

```c
#pragma config ICESEL = ICS_PGx1
```

### MPLAB Snap eight-pin connector

| Snap pin | Signal | Use |
|---:|---|---|
| 1 | TVPP/MCLR | MCLR |
| 2 | TVDD | 3.3 V sense |
| 3 | GND | Ground |
| 4 | PGD | PGED1 |
| 5 | PGC | PGEC1 |
| 6 | AUX | Normally NC |
| 7 | TDI | NC unless using JTAG |
| 8 | TMS | NC unless using JTAG |

### PICkit 4

Use its standard ICSP signals in the same order for the first six positions. Verify the triangle/pin-1 marking on the PICkit 4 cable or adapter.

## 6. ICSP loading rules

PGEC1 and PGED1 should be:

- short and directly routed
- free of capacitors
- free of LEDs
- free of pull-up or pull-down resistors
- free of series diodes
- disconnected from circuits that strongly drive the lines during programming

## 7. Powering the target

Preferred initial setup:

1. Disconnect USB from the PCB.
2. Power the PCB from a current-limited regulated 3.3 V supply.
3. Connect board ground to programmer ground.
4. Connect TVDD as a voltage-sense input.
5. Do not enable tool-supplied power.

Start with a conservative current limit, then raise it only after confirming no short or incorrect orientation.

Never allow the PICkit/Snap, USB input, and external supply to fight each other.

## 8. Pre-program electrical checks

With no MCU or with power removed:

- [ ] No short between 3.3 V and GND.
- [ ] ICSP pin 1 reaches MCLR.
- [ ] ICSP pin 4 reaches PGED1.
- [ ] ICSP pin 5 reaches PGEC1.
- [ ] Header pin 2 reaches 3.3 V.
- [ ] Header pin 3 reaches GND.
- [ ] D+ and D- are not swapped.
- [ ] VBUS reaches MCU VBUS sensing circuitry.
- [ ] VUSB3V3 is connected exactly as required by the data sheet.
- [ ] Crystal is connected to OSC1/OSC2 with the intended capacitors.
- [ ] VCAP is not shorted to VDD.

With power applied:

- [ ] 3.3 V is within the MCU operating range.
- [ ] VCAP rises to the expected internal-regulator level.
- [ ] MCLR idles high.
- [ ] Programmer reports a valid target voltage.

## 9. First connection sequence

1. Remove all power.
2. Insert MCU and latch clamshell.
3. Connect PICkit 4 or Snap to ICSP.
4. Connect external 3.3 V and ground.
5. Apply 3.3 V.
6. Open MPLAB IPE.
7. Device: `PIC32MX534F064H`.
8. Tool: PICkit 4 or Snap.
9. Click **Connect**.
10. Confirm the tool reads the correct device ID.
11. Perform a blank check before first programming.

The expected device ID family value for PIC32MX534F064H is `0x04400053`; MPLAB normally handles this automatically.

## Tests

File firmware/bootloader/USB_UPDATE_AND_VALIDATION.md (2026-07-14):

# USB firmware update and validation

## 1. Prepare the test application

Build the bootloader-aware test application but do not program it with PICkit/Snap.

Production HEX location:

```text
generated_projects/test_app_pic32mx534.X/
  dist/default/production/
    test_app_pic32mx534.X.production.hex
```

Run the layout checker first:

```powershell
python scripts\hex_layout.py `
  --mode application `
  generated_projects\test_app_pic32mx534.X\dist\default\production\test_app_pic32mx534.X.production.hex
```

Proceed only when it reports `PASS`.

## 2. Start the USB bootloader

Any of these conditions should keep the bootloader active:

- no valid application exists at `0x9D008000`
- the optional force-boot switch is held during reset
- the application writes four copies of `0x5048434D` to the first 16 SRAM bytes, then performs a software reset

For first use, Program Flash after the bootloader should be blank, so no switch is required.

## 3. Open Microchip Unified Host

Typical location in a Harmony 3 installation:

```text
<harmony3_path>\bootloader\tools\UnifiedHost-*\UnifiedHost-*.jar
```

Launch example:

```powershell
java -jar C:\microchip\harmony\v3\bootloader\tools\UnifiedHost-1.20.0\UnifiedHost-1.20.0.jar
```

The actual versioned directory may differ.

Configure:

```text
Architecture: PIC32
Protocol: USB
Product ID: 3C
```

Select the enumerated USB HID bootloader.

## 4. Program the application

1. Load the test application's production HEX.
2. Open the Unified Host console.
3. Click **Program Device**.
4. Wait for erase, write, and verify to complete.
5. Allow the host to reset the board or manually reset it.
6. Confirm the application LED blinks.

Close Unified Host before trying to program the MCU through MPLAB X/IPE again, because both tools may contend for the device.

## 5. Validate all entry paths

### Test A: Blank application

1. Erase/program only the bootloader through ICSP.
2. Connect USB.
3. Confirm HID enumeration.
4. Result: pass when Unified Host detects Product ID `3C`.

### Test B: USB programming

1. Load the test application through Unified Host.
2. Reset.
3. Confirm the test LED blinks.
4. Result: proves receive, erase, write, verify, reset, and jump.

### Test C: Application software request

1. Call `Bootloader_RequestAndReset()` from the running application.
2. Confirm the LED stops blinking and HID bootloader re-enumerates.
3. Program again.
4. Result: proves the 16-byte RAM trigger and software reset.

### Test D: Hardware force switch

Applicable only after mapping the switch in `bootloader_board.h`.

1. Hold the switch.
2. Reset or power-cycle.
3. Confirm bootloader enumeration rather than application execution.
4. Release the switch before the next reset.

### Test E: Power-cycle persistence

1. Load the application.
2. Remove all power.
3. Reapply power without holding force boot.
4. Confirm the application starts.

### Test F: ICSP recovery

1. Intentionally load a harmless application image that does not request bootloader mode.
2. Reprogram the bootloader through ICSP.
3. Confirm USB bootloader enumeration returns.

## 6. Record objective evidence

Save:

- MPLAB X build log
- bootloader `.map`
- test application `.map`
- `verify_project.py` output
- both `hex_layout.py` outputs
- MPLAB IPE programming log
- Unified Host console log
- USB VID/PID screenshot
- measured 3.3 V, VCAP, and crystal frequency
- LED behavior video or test notes
- MCU lot/revision and socket cycle count

## 7. Acceptance criteria

| Test | Required result |
|---|---|
| ICSP device detection | Correct PIC32MX534F064H |
| ICSP program/verify | Pass |
| USB enumeration | HID, VID `04D8`, PID `003C` |
| Bootloader HEX boundary | No PFM data at or above `0x1D008000` |
| Application HEX boundary | No PFM data below `0x1D008000`; no Boot Flash/config data |
| USB program | Erase/write/verify pass |
| App start | Test LED blinks |
| RAM trigger | Returns to bootloader |
| Force switch | Returns to bootloader, when fitted |
| Power cycle | Application restarts |
| ICSP recovery | Pass |

## 8. Failure isolation

### Programmer cannot detect device

Check MCLR, TVDD, ground, PGEC1/PGED1 mapping, socket orientation, VCAP, and all power pins.

### Programmer detects wrong/unstable voltage

Check external 3.3 V supply, common ground, TVDD wiring, current limit, and power-source contention.

### Bootloader programs but USB does not enumerate

Check:

- 8 MHz oscillator actually starts
- PLL/configuration bits
- 48 MHz USB clock
- VBUS input
- VUSB3V3 connection
- D+/D- polarity
- USB connector orientation
- ESD/filter parts
- ground plane and differential routing
- VID/PID descriptor
- Windows Device Manager hardware ID

### Application upload succeeds but does not run

Check:

- application linker reset at `0xBD008000`
- EBASE at `0x9D009000`
- application HEX contains data at physical `0x1D008000`
- no config words in application HEX
- application clock assumptions match bootloader configuration
- test LED mapping and polarity

### Application overwrites bootloader

Stop using that HEX. Fix the application linker and verify it with `hex_layout.py` before another USB update.

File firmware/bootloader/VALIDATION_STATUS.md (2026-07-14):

# Validation status

## What was checked before delivery

- The memory map was derived from the target's 64 KiB Program Flash and 16 KiB SRAM.
- The 32 KiB bootloader reservation follows Microchip's PIC32MX USB HID example.
- The application reset page and EBASE split follows Microchip's generated PIC32MX application linker:
  - application jump/reset page at `0x9D008000`
  - EBASE/code at `0x9D009000`
- The first 16 SRAM bytes are reserved for the standard `0x5048434D` boot request.
- The ICSP mapping uses PGEC1/PGED1 and matches `ICESEL = ICS_PGx1`.
- The 8 MHz oscillator configuration produces 80 MHz SYSCLK and the required 48 MHz USB clock.
- The trigger override compiles and passes host unit tests.
- The HEX parser passes valid/invalid synthetic image tests.
- Static scripts reject stale 512 KiB/64 KiB-RAM reference settings.

## What was not possible in this environment

- Running MPLAB XC32
- Running MCC/Harmony code generation
- Compiling the final generated MPLAB projects
- Programming a physical PIC32MX534F064H
- Measuring oscillator or USB electrical behavior
- Confirming the exact board LED and switch GPIOs from the low-resolution schematic image
- Pushing directly to the GitHub repository

## Release gate

Do not tag this firmware as hardware-validated until all items below are complete:

- [ ] Bootloader project generated for exact device
- [ ] Bootloader XC32 production build passes
- [ ] Test application XC32 production build passes
- [ ] Static project verification passes
- [ ] Both HEX layout checks pass
- [ ] PICkit 4 program/verify passes
- [ ] Snap program/verify passes, when Snap support is required
- [ ] USB HID enumerates as `04D8:003C`
- [ ] Unified Host programs and verifies the test application
- [ ] Test application runs after reset and power cycle
- [ ] RAM trigger returns to bootloader
- [ ] Hardware switch trigger passes, when fitted
- [ ] ICSP recovery passes

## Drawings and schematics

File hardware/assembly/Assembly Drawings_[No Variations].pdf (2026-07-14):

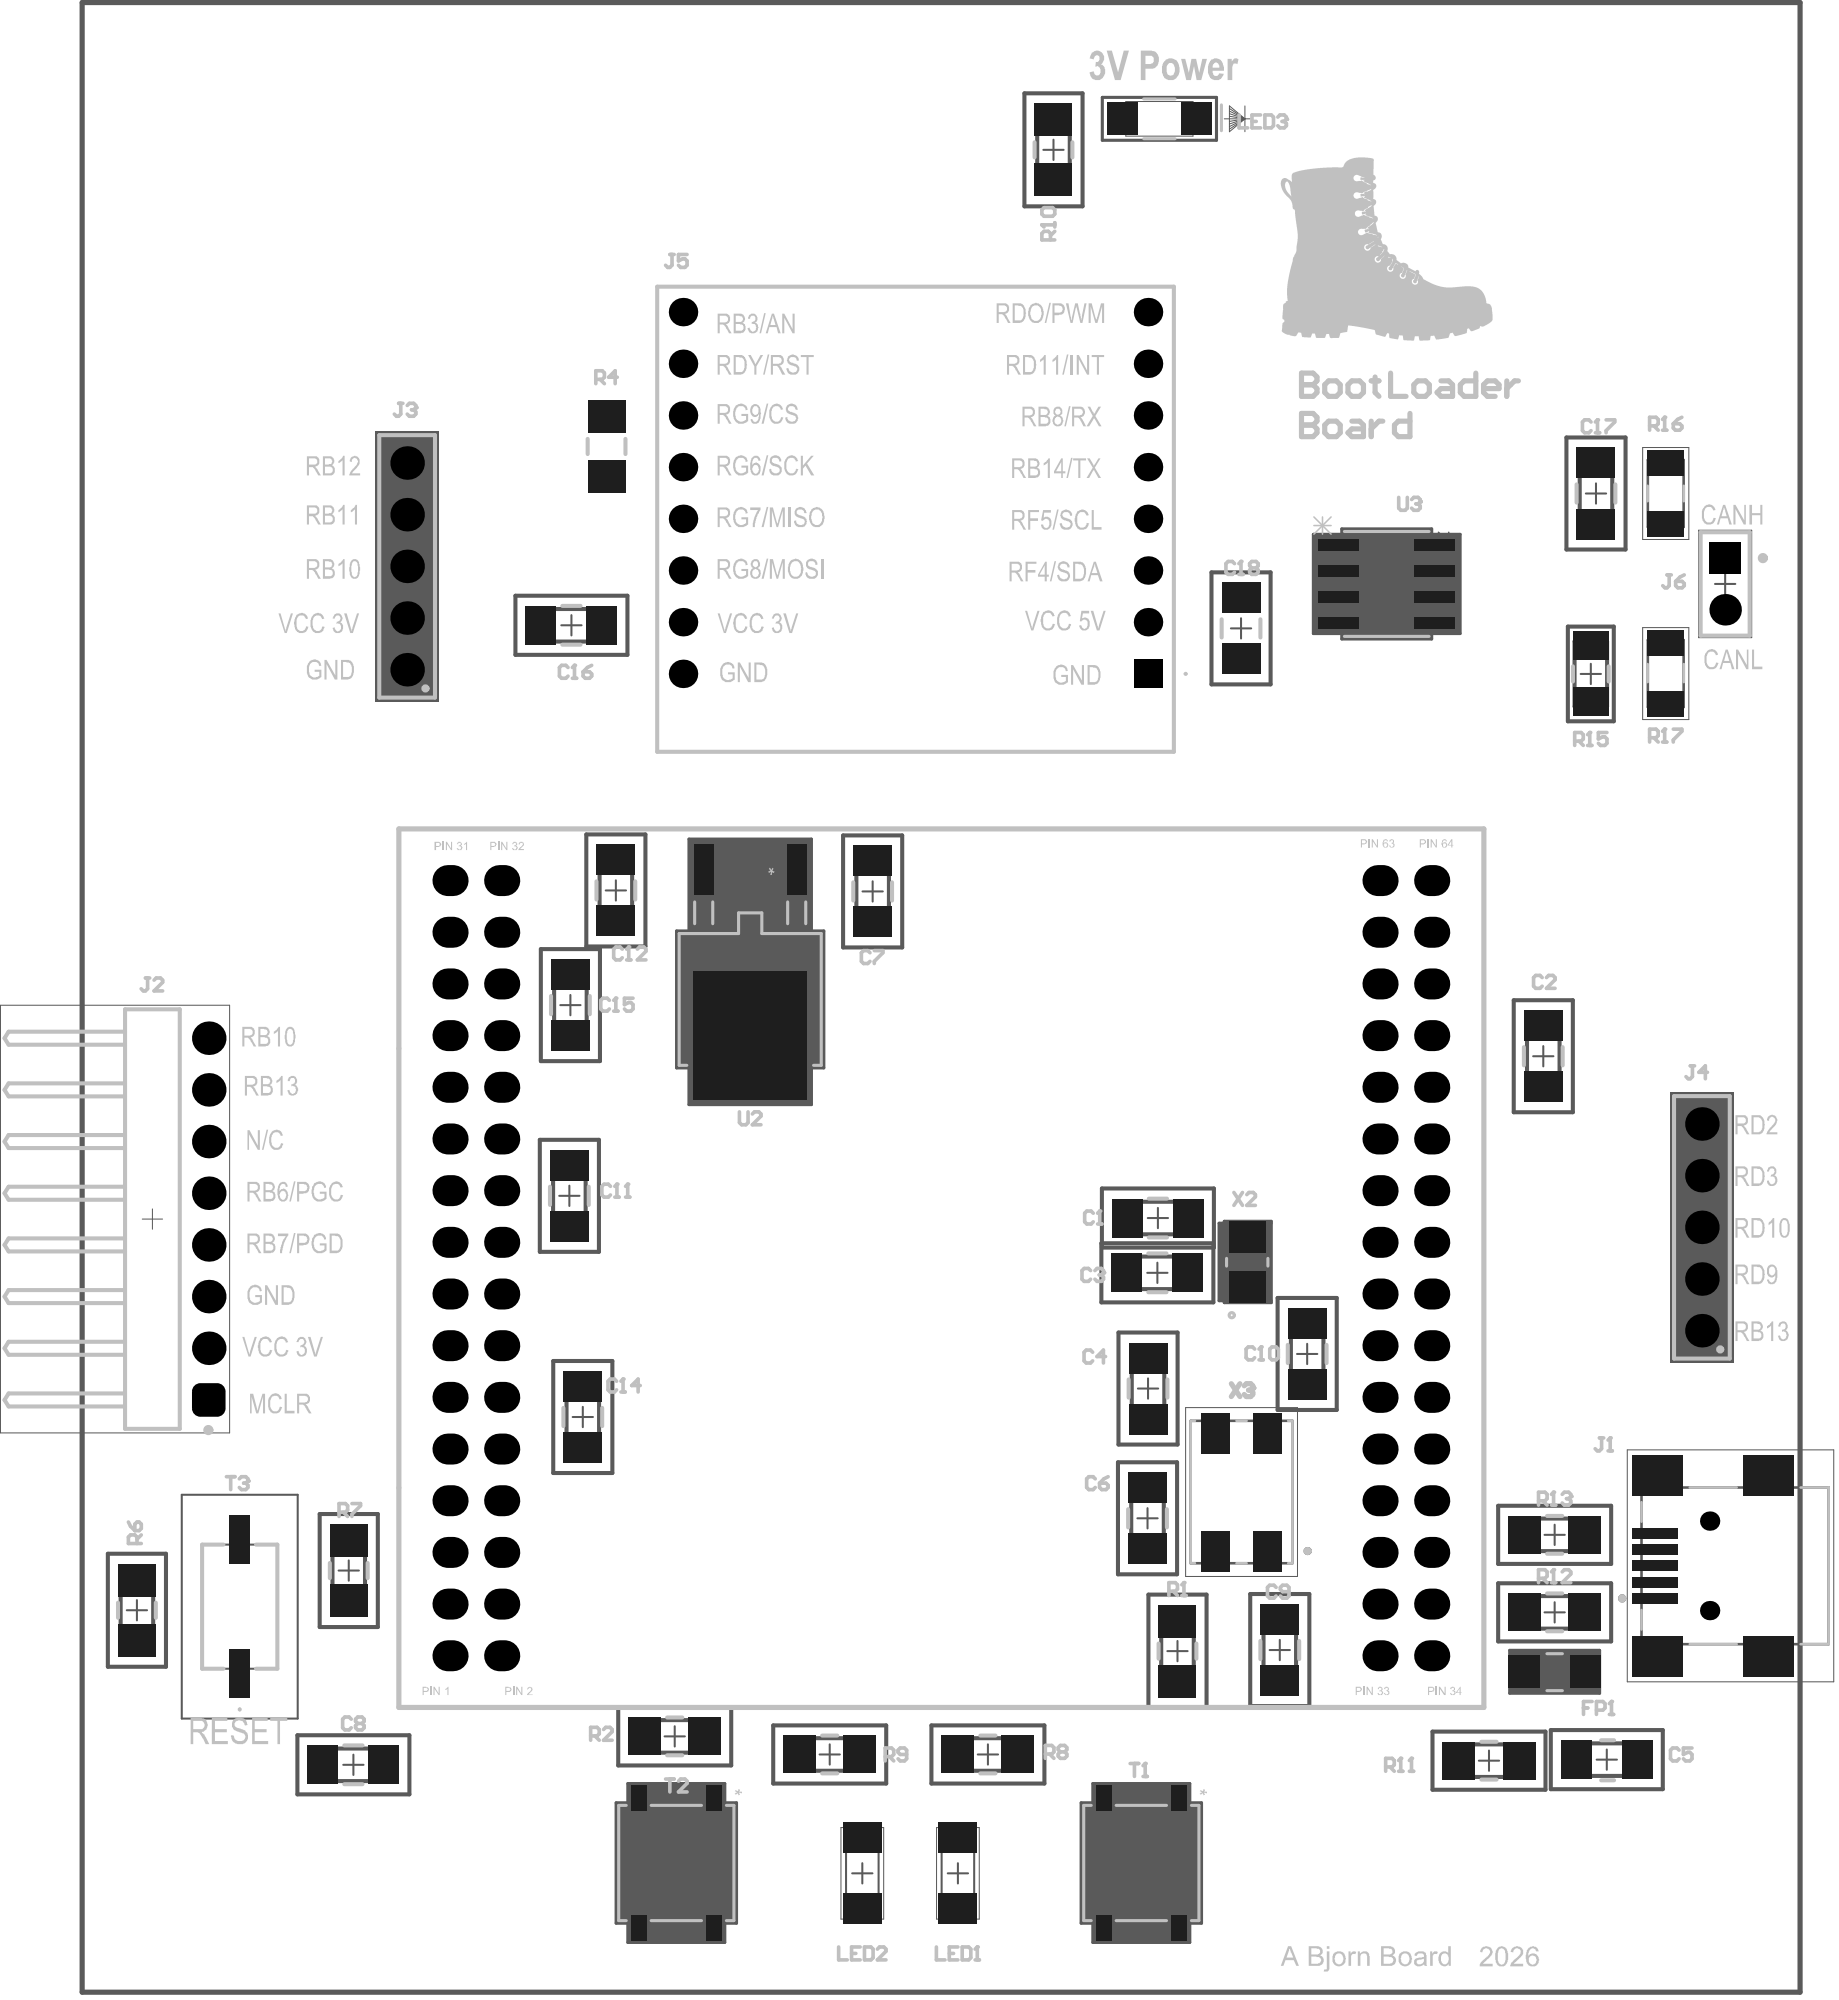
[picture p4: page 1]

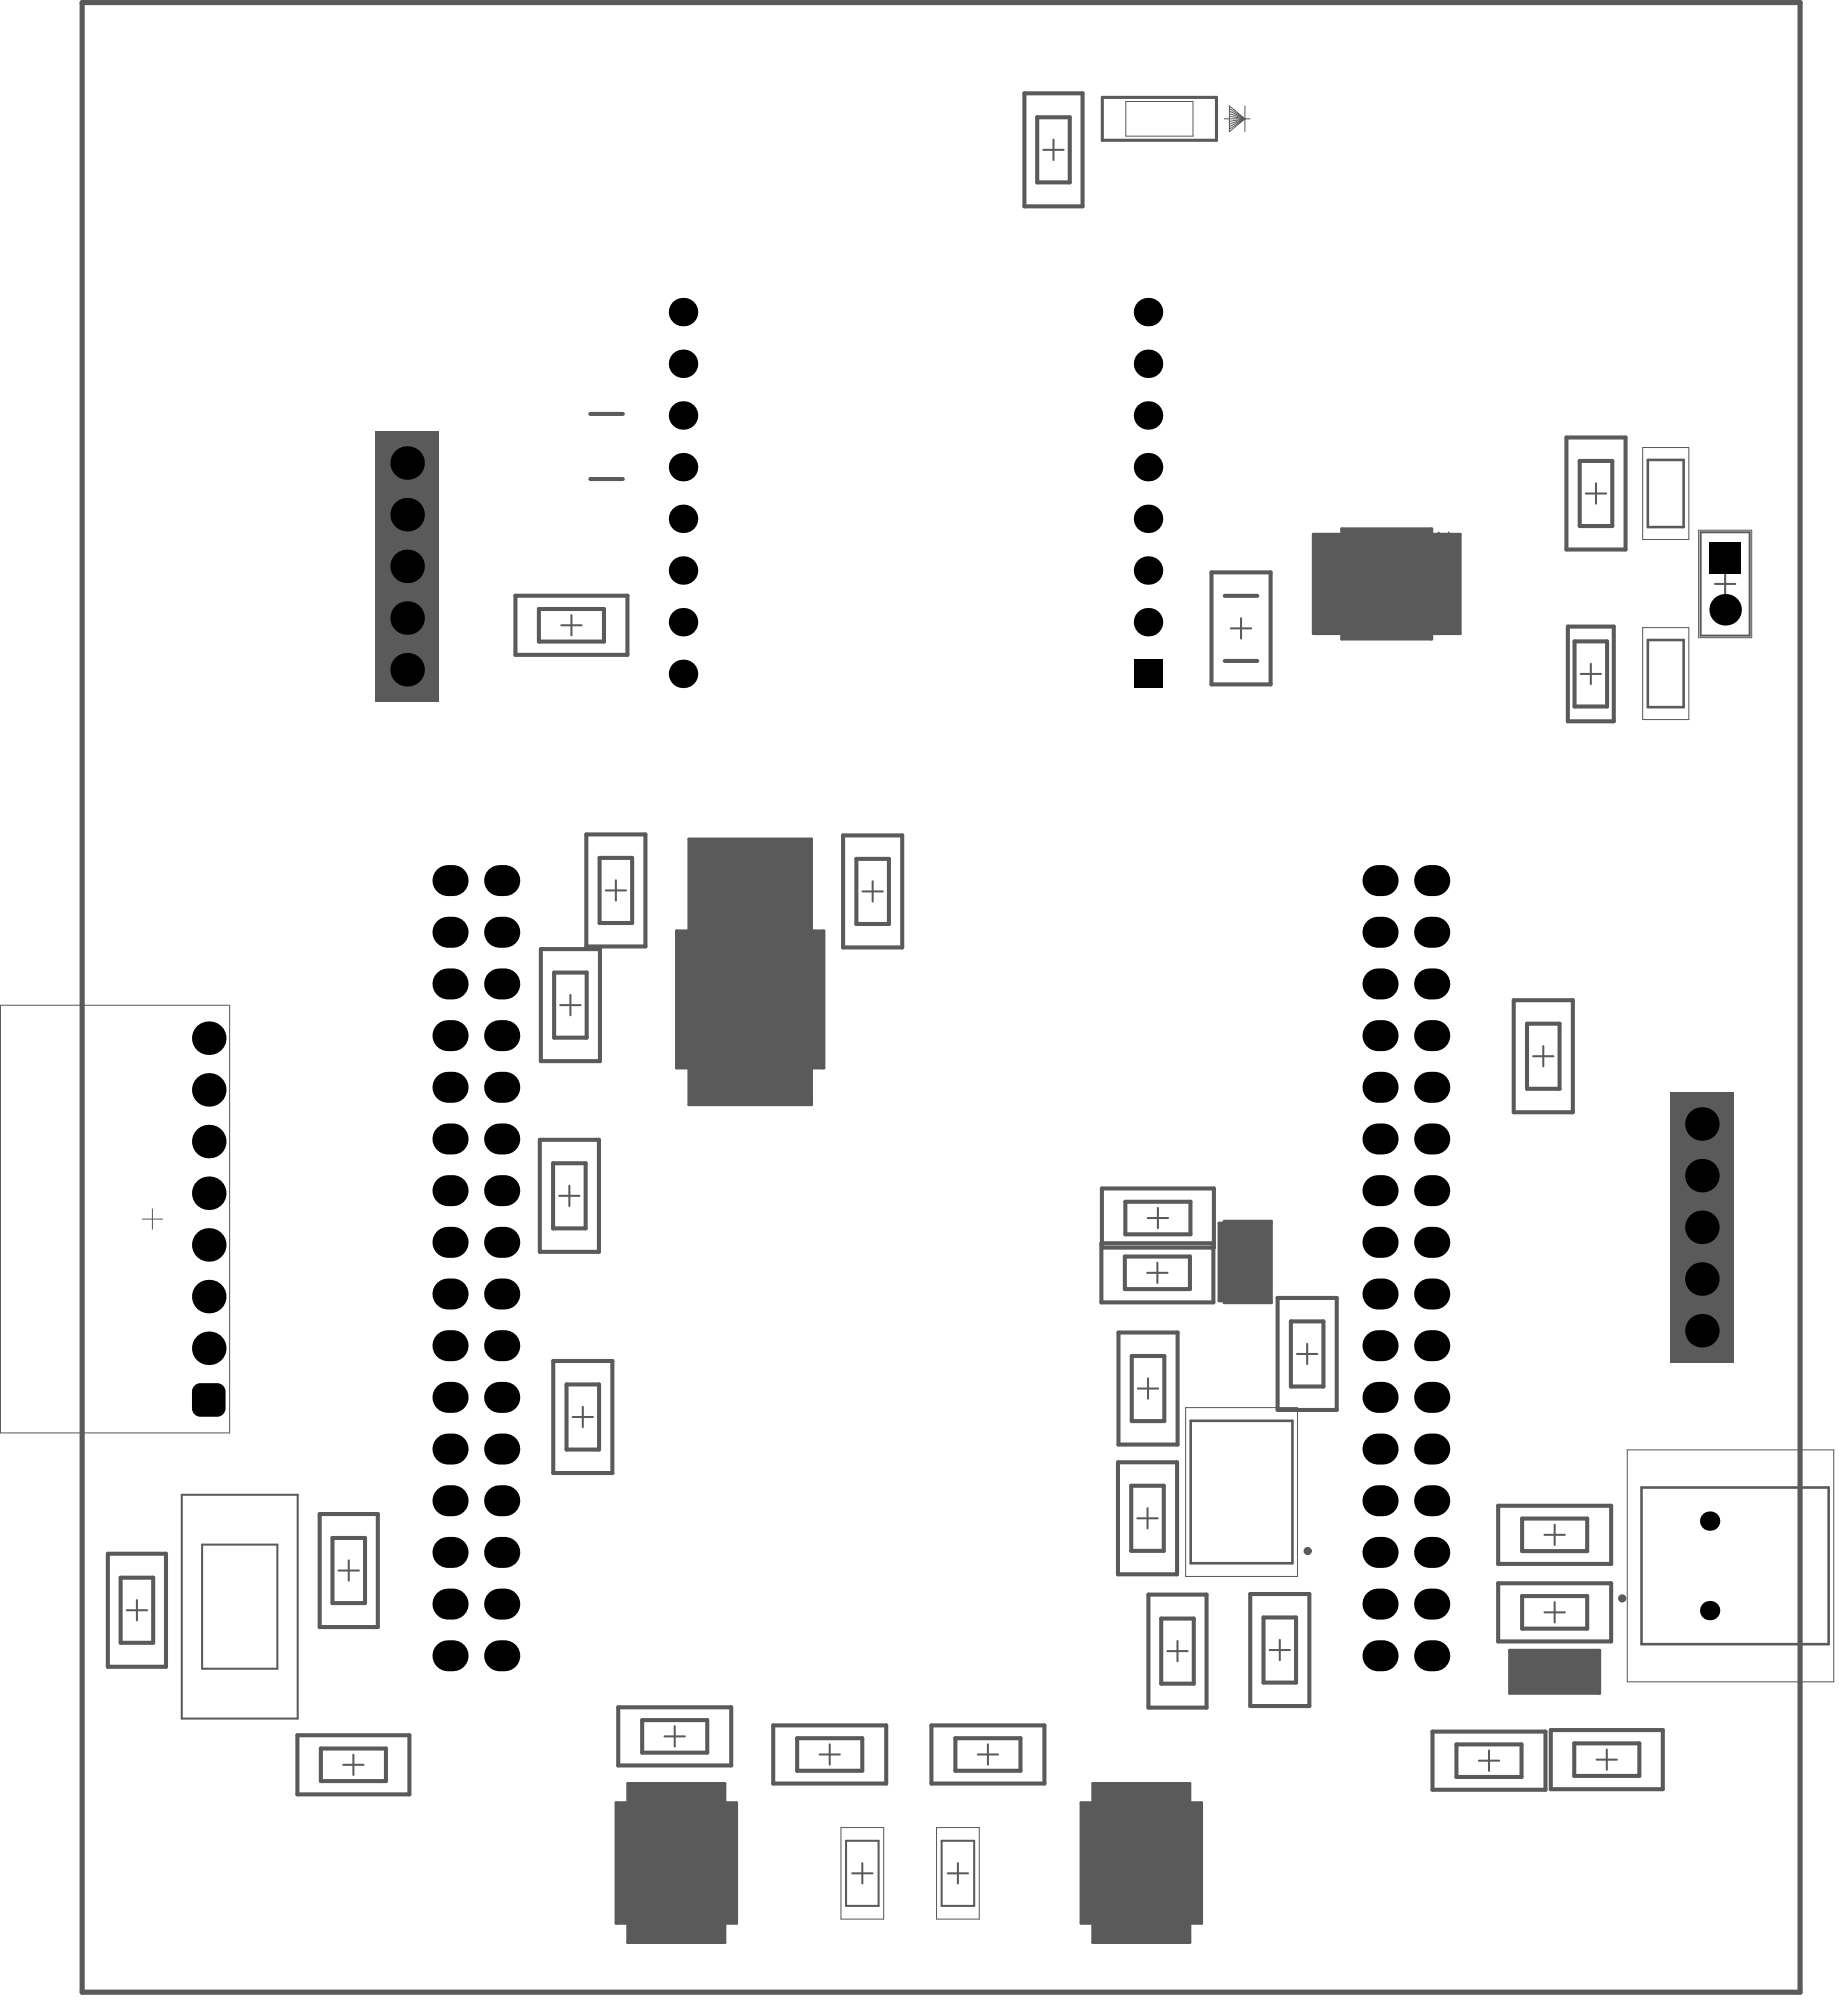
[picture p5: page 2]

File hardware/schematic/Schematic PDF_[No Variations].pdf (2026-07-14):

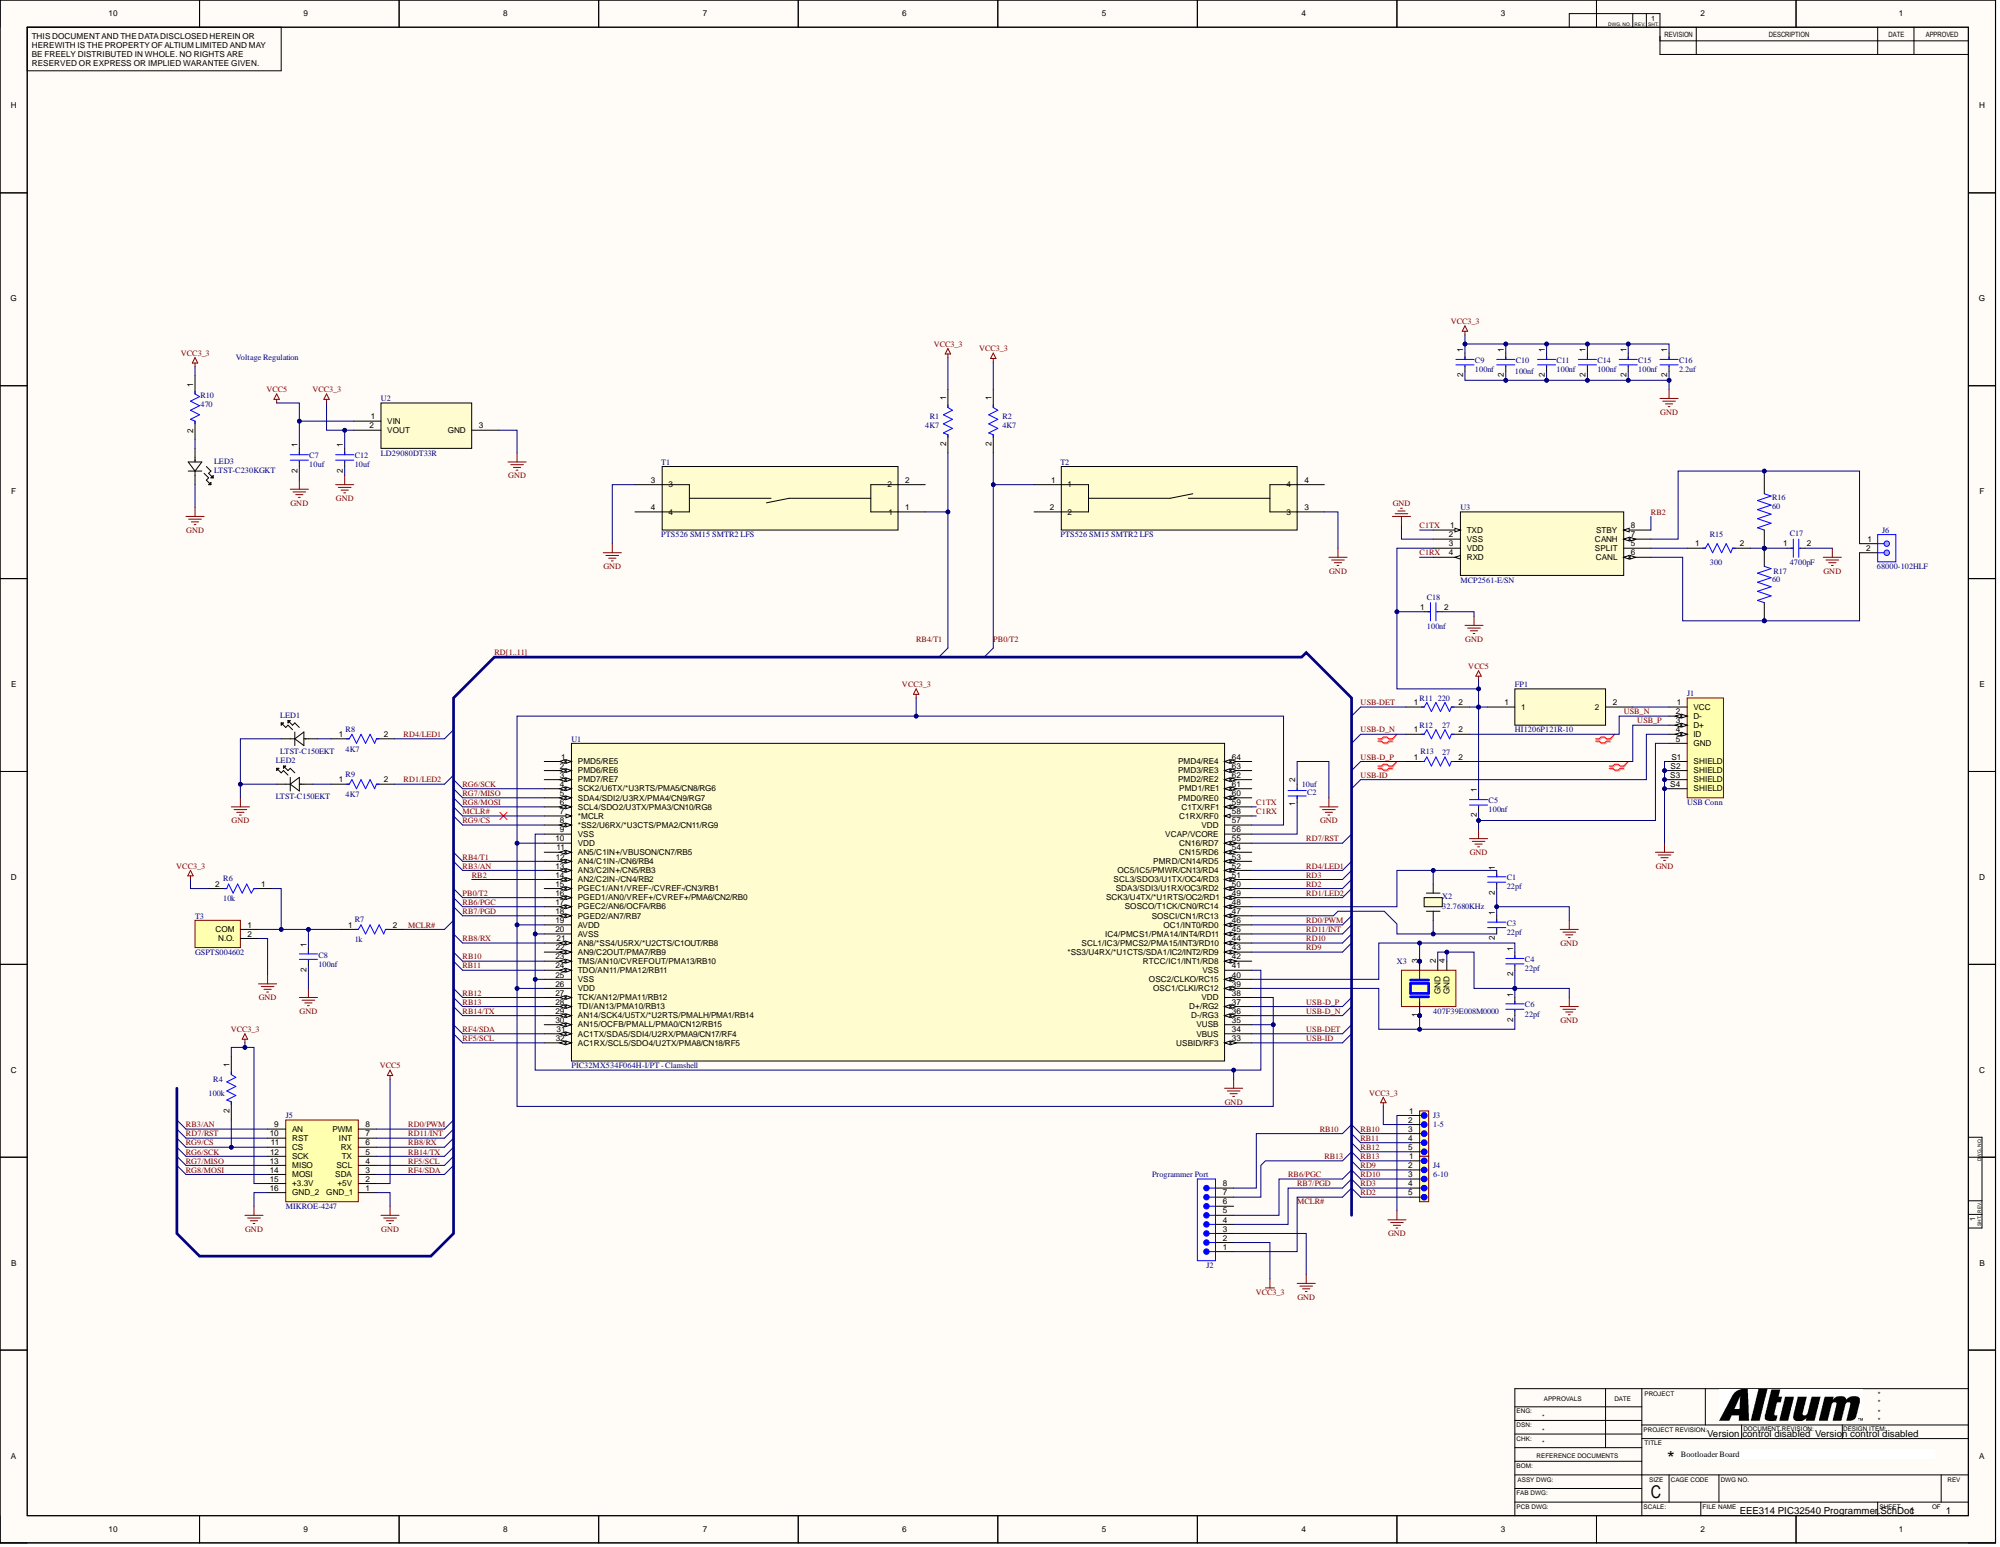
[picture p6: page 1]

DWG . N O . | R E V | 1 . S H T.

T H IS DOC U MEN T AN D T HE D ATA D ISCLOSED HEREI N OR HEREW I T H IS T HE PROPER TY OF ALT I U M LI M I TED AN D M AY IST HOLE. NO IGH TS ARE BE F REELY D R IBU TED I N W R RESERVED OR EXPRESS OR I MPLIED WARAN TEE GIVEN . | VCC3 _ 3 | REVISI O N | DESCRIPTI O N | DATE | APPROVED

USB-D _P 1 | | | 5

AREV. SHT. DWG. NO.

DATE | PRO JECT | **** APPROVALS

ENG :
** DSN:

PRO JECT REVISION: Version | DOCUMENT REVISION: control disabled Version control disabled | DESIGN ITEM :
TITL E *

CHK: *

ASSY DWG : | SIZE C | CAGE CODE | DWG NO . | REV

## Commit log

2026-07-13 Initial commit: PIC32MX programmer PCB project
2026-07-13 Add Altium schematic, PCB, libraries, BOM, and STEP model
    [EEE314 PIC32540 Programmer.PcbLib, EEE314 PIC32540 Programmer.SCHLIB, EEE314 PIC32540 Programmer.SchDoc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]
2026-07-13 Add complete Altium project files
    [EEE314 PIC32540 Programmer - Copy for John T Lewis.PrjPcb]
2026-07-14 Add fabrication, assembly, BOM, schematic, and STEP files
    [BOM_[No Variations].csv, STEP_[No Variations] for PCB-BL-2.PcbDoc.step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]
2026-07-14 Revise LED and force-boot switch documentation
    Updated the description for LED and force-boot switch support in the README.
2026-07-14 Update BOM 💣
    [PIC32MX_Programmer_Completed_BOM.xlsx]
2026-07-14 Rename BOM_[Altium_Extract].csv file
    [BOM_[Altium_Extract].csv]
2026-07-22 Replace image in README with new programmer board
    Updated the image in the README to a new source.
2026-07-23 Revise PCB manufacturing and project status details
    Updated the README to reflect changes in PCB manufacturing and assembly status.
2026-07-28 Add BootLoader Board Poster link to README
    Added link to BootLoader Board Poster V2 PDF in README.
2026-11-13 Record hardware bring-up: USB bootloader and LED test app working
    Bring-up on 2026-11-13 with an MPLAB Snap and MPLAB IPE v6.30: the
    PIC32MX534F064H programs over ICSP, the Harmony USB HID bootloader runs
    from the 8 MHz crystal and enumerates, and Unified Host loaded an LED
    test app that runs.
    Fixes found on hardware:
    - Clock: MCC defaulted to FNOSC=FRCPLL / POSCMOD=OFF, which leaves the
    PIC32MX5xx USB PLL without a clock. Document PRIPLL/HS and make
    verify_project.py reject the bad settings.
    - ICSP channel: the Programmer Port (J2) is wired to RB6/RB7, i.e.
    PGEC2/PGED2, not PGEC1/PGED1. Correct the docs, config_bits_8mhz.c and
    verify_project.py to ICS_PGx2.
    - Document the IPE Snap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
2026-11-13 Add T2 update button, PID 0x003C and a team guide
    Bootloader (rebuilt and tested on hardware, IPE checksum FF12BE4E):
    - bootloader_board.h now maps the real board: hold T2 (RB0, pin 16)
    during reset to enter update mode; LED2 (RD1) stays on while the
    bootloader runs. RB0/AN0 is switched to digital before it is read.
    - First 16 bytes of SRAM reserved so an app can request the bootloader.
    - USB Product ID 0x003C, ICESEL = ICS_PGx2.
    - Host tests cover the switch, the LED and the RAM request with a mock
    xc.h.
    Hardware issue found: T1 is not connected to the MCU. In the schematic
    netlist the RB4/T1 label is not joined to the switch; T1 sits on a net
    with R1, R15 and the MCP2561 SPLIT pin.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
2026-11-13 Add Lab Tech guide and Load Bootloader tool for loading many chips
    Part 1 guide for lab leads (docs/lab-tech-guide): what to buy (Snap
    micro-USB, board mini-USB), installing MPLAB X/IPE, downloading the repo
    (ZIP, unblock, extract, Send to Desktop), connecting the Snap to J2,
    seating chips in the clamshell, loading batches, the LED test, an
    errors table and a manual IPE fallback. It now comes before the team
    guide in the README.
    tools/load-bootloader/"Load Bootloader.cmd": checks the PC (firmware
    SHA-256, ipecmd, Snap on USB, IPE not holding the Snap), then loops over
    chips: program + verify through the Snap, confirm the bootloader runs by
    waiting for USB 04D8:003C, print PASS/FAIL with pla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
2026-11-13 Add annotated board and chip photos to the guides
    - board-overview.jpg: J2 Programmer Port with pin 1 (MCLR) at the bottom
    next to RESET, RESET (T3), T2 update button, T1 (not wired), LED2/LED1,
    J1 mini-USB, 3V power LED, clamshell.
    - chip-in-socket.jpg: chip seated with the pin-1 dot bottom-left (corner
    nearest T2 and the "1 2" label), lid hinge at the top.
    - Lab Tech guide: "Know the board" table, exact Snap orientation from the
    J2 silkscreen, exact chip orientation; all photo placeholders replaced.
    - Team guide: board photo in the Buttons section.
2026-11-13 Test C passes; add MCC patch script; fix test-app build
    Test C (app requests the bootloader): the LED test app now enters update
    mode when T2 (RB0) is pressed while it runs. It writes 0x5048434D to the
    first 16 bytes of SRAM and software-resets; the bootloader sees the
    request and stays. Tested on hardware 2026-11-13: LED2 steady and
    USB 04D8:003C back without pressing RESET. The app also enables RB0's
    internal pull-up so boards without a button there can't trigger it.
    tools/mcc-patch/Apply-BootloaderPatches.ps1: run after MCC Generate.
    Re-applies FNOSC=PRIPLL, POSCMOD=HS, ICESEL=ICS_PGx2, USB PID 0x003C,
    the btl.ld RAM reservation, and the app.c/bootloader_board.h overrides,
    then runs veri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
2026-11-14 Add the bootloader MPLAB X project source
    firmware/bootloader/generated_projects/ now holds the full bootloader:
    the MPLAB X project (Bootloader.X: nbproject, MCC configuration in
    Bootloader_default, Harmony package manifest) and src/ (MCC/Harmony 3
    generated bootloader, USB device + HID, NVM, startup, btl.ld, plus this
    board's app.c and bootloader_board.h). All board changes from the patch
    script are applied; verify_project.py passes on it.
    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
